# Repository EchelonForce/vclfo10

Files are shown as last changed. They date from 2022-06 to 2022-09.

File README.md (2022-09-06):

# Eurorack LFO VCLFO10 

This is a PCB for a eurorack LFO based on the VCLFO10 chip from Electric Druid.

Full writeup here: https://www.robotdialogs.com/2022/09/eurorack-lfo-module-vclfo10.html

This work is licensed under a Creative Commons Attribution-NonCommercial-ShareAlike 4.0 International License. https://creativecommons.org/licenses/by-nc-sa/4.0/

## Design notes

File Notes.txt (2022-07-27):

v1 issues
 - alternate led stuff should go to output of the lfo filter, it doesn't work with the pwm output of the chip because it doesn't go negative. used a 10k 1/4 watt instead of R51 to go from led stuff to R73, see photo.
 - switches operate backwards from expected, so flipping them on pcb would improve that.
 - zero adjust pot seems to be backwards, would make more sense if it was reversed.

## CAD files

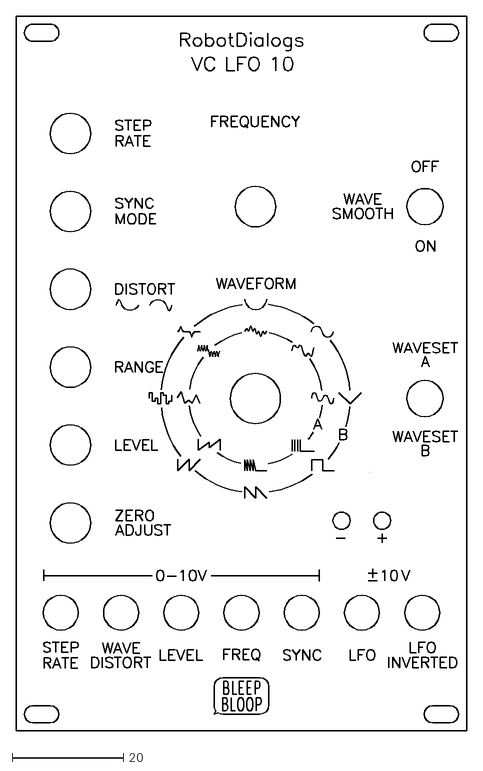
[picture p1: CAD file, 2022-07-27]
front_panel_v1/vclfo10_v1_front_panel_v1.1_engraving.dxf
80.9 x 128.4

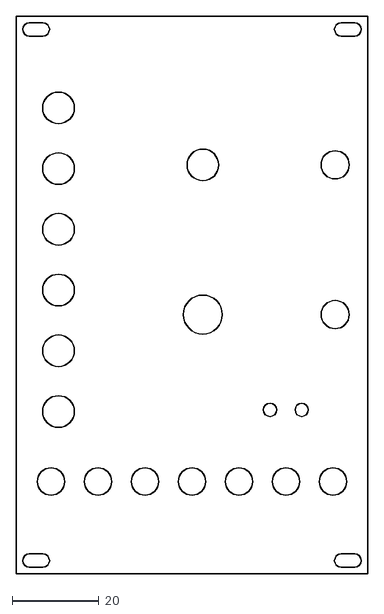
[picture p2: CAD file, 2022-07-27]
front_panel_v1/vclfo10_v1_front_panel_v1.1_no_engraving.dxf
81.0 x 128.5

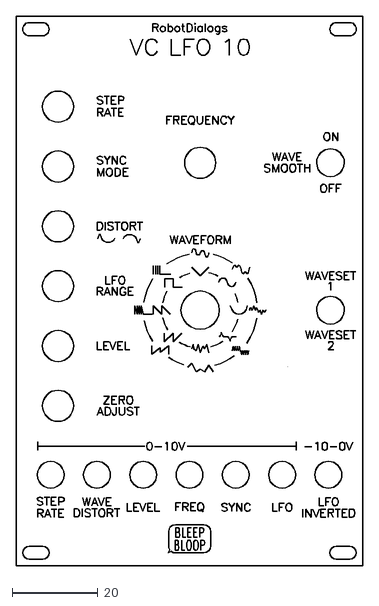
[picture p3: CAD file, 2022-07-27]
front_panel_v1/vclfo10_v1_front_panel_v1_engraving.dxf
80.9 x 128.4

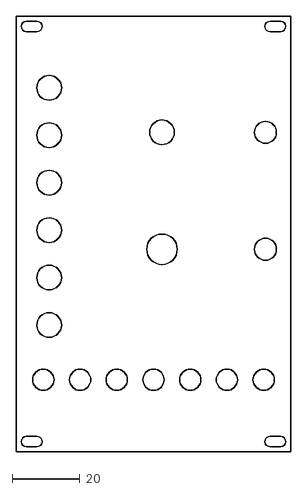
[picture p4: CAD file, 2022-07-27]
front_panel_v1/vclfo10_v1_front_panel_v1_no_engraving.dxf
81.0 x 128.5

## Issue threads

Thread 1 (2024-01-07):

Q's regarding reworking this LFO

KeLaiFu, 2024-01-07:
Hey, first of all, thanks for sharing this monster of an LFO. I have just built it and it's sat in my rack intimidating any 4hp LFOs I have nearby.
I have a few questions, I hope here is an appropriate place to ask.
Firstly, why did you opt for the 358 opamps over the usual TL07X ones?
Second, If I wanted to remove a CV in jack, would it be as simple as just removing it from the schem, as the jacks seem to just patch on to the input coming from the potentiometer.

I plan to make a slightly smaller, reformatted layout to match my other modules, I've got a rough plan but I always end up with a spare jack lying around ruining the feng shui, so I was hoping I could take one out, and maybe use some quad opamps to get the parts down a little.

EchelonForce, 2024-01-11:
Hi, glad to here someone is trying out the design! And yep it's fine to ask here or over on the website comments, whatever works.
I would expect 358s and TL07x's are interchangeable here. I probably just had a lot more 358s at the time. In the tinyurl's on the schematic there are simulators for the sub-circuits so you could experiment with the op-amp parameters in there, but at audio/lfo frequencies I don't think it matters.
You should be able to remove any of the CV jacks, the schematic has switched jacks but it doesn't use that function so removing a jack is just like removing a cable. If there's no jack then that input to the chip doesn't really need to be supplied by +/-12V or run through op-amps, a potentiometer hooked to 5V would work (I think that's what's in the chip's reference schematic).

This was one of my earlier designs. There's a lot I would probably do differently now, quad op-amps would be one of those things.

Make sure you look through the v1 issues on the website: https://www.robotdialogs.com/2022/09/eurorack-lfo-module-vclfo10.html

KeLaiFu, 2024-01-15:
Thanks for the reply.
Yep, currently your overkill LFO found 3 homes here in our SDIY group and I used your mixer layout and a few others in my own modules, so your work is finding a home.

I appreciate the info about the module, I will experiment a little, if I am feeling brave I may use some quad opamps as that would be a help to my revised layout.

Thanks again, and hope to see more added to Robot Dialogs...

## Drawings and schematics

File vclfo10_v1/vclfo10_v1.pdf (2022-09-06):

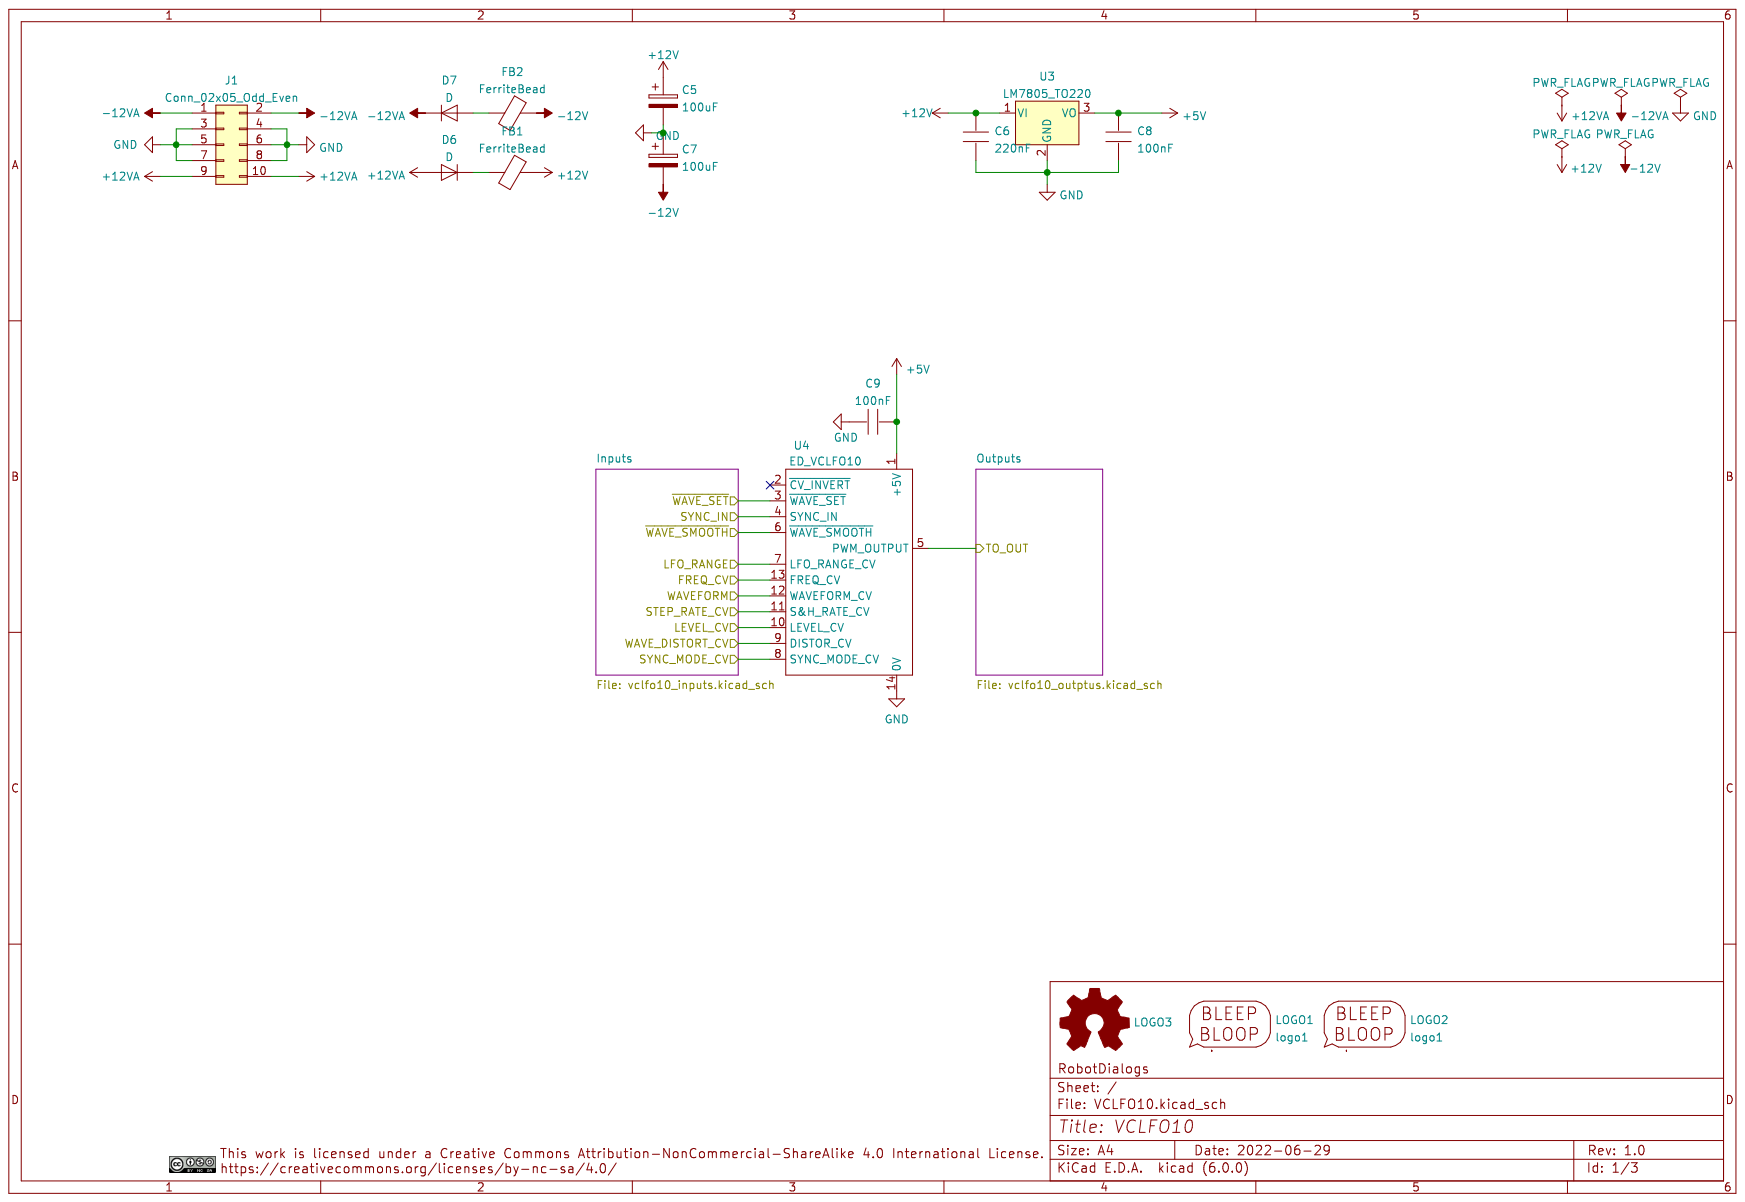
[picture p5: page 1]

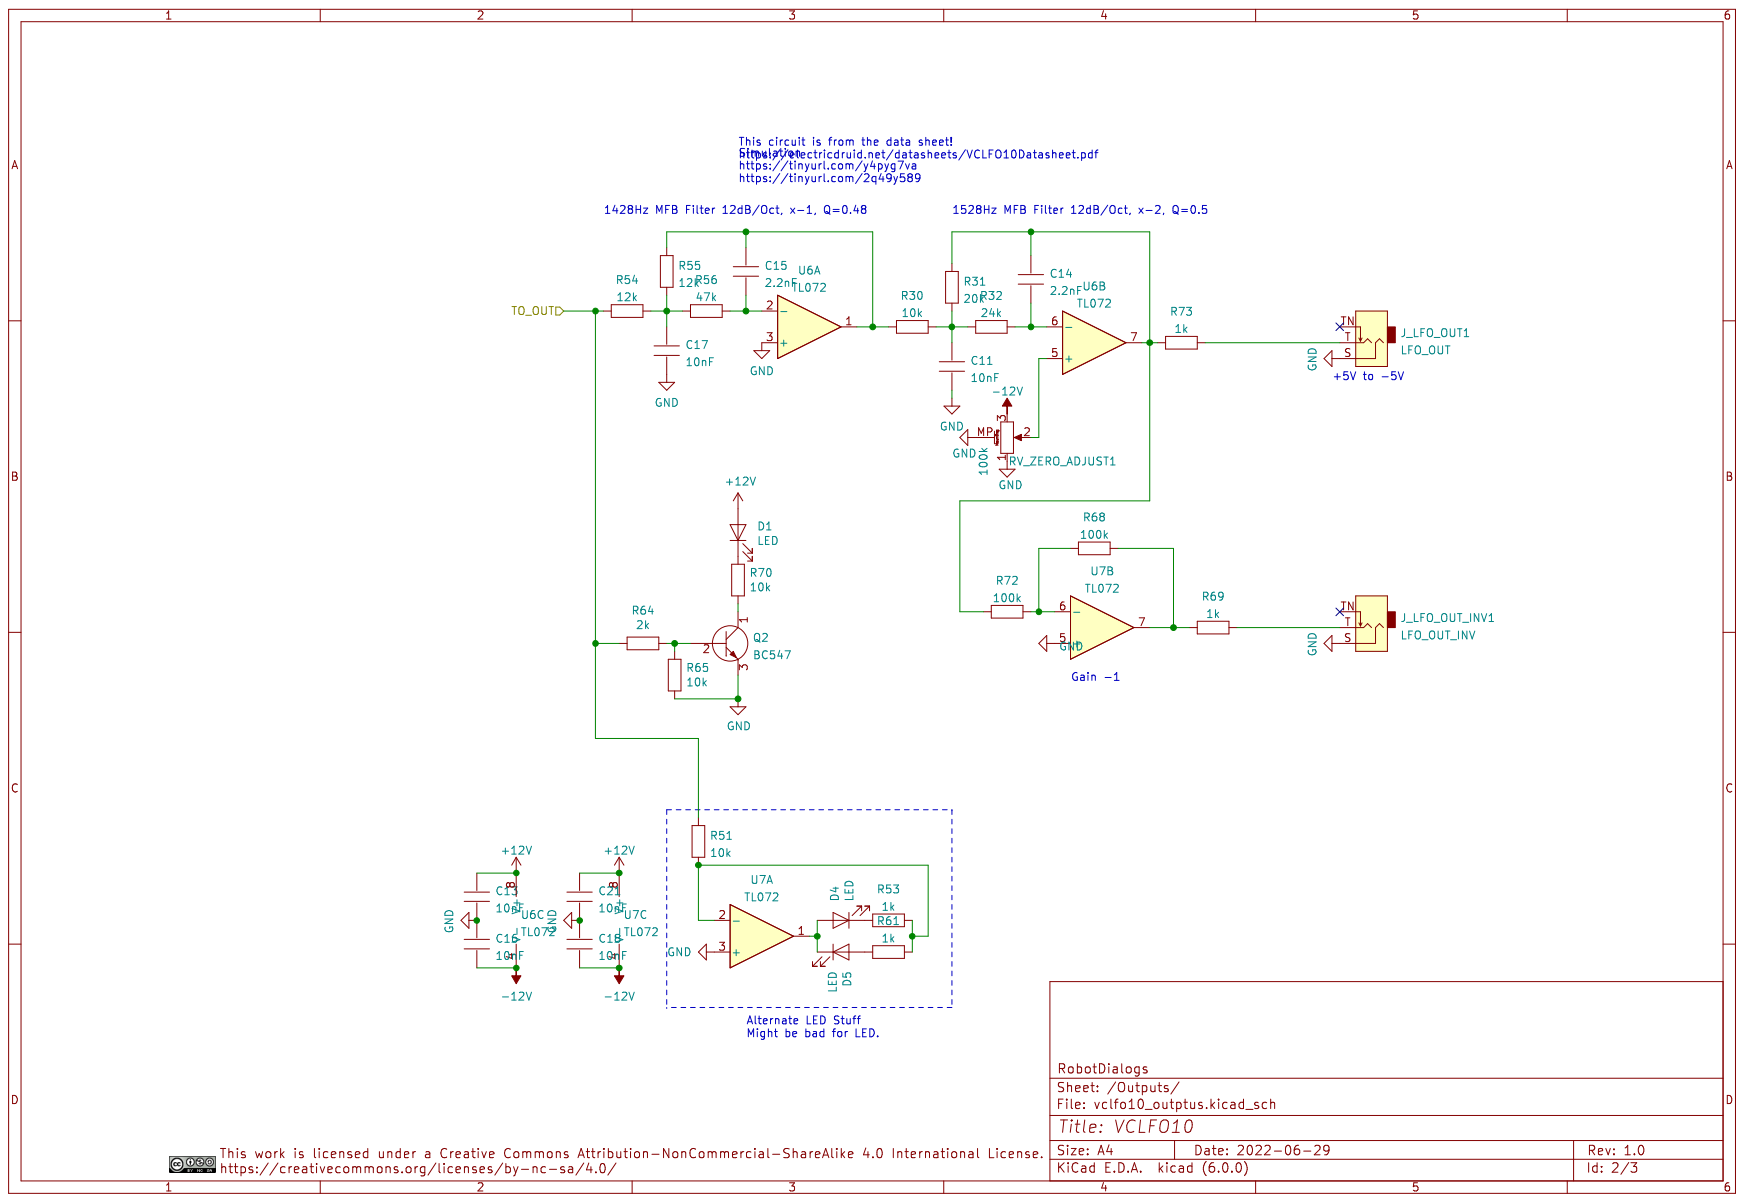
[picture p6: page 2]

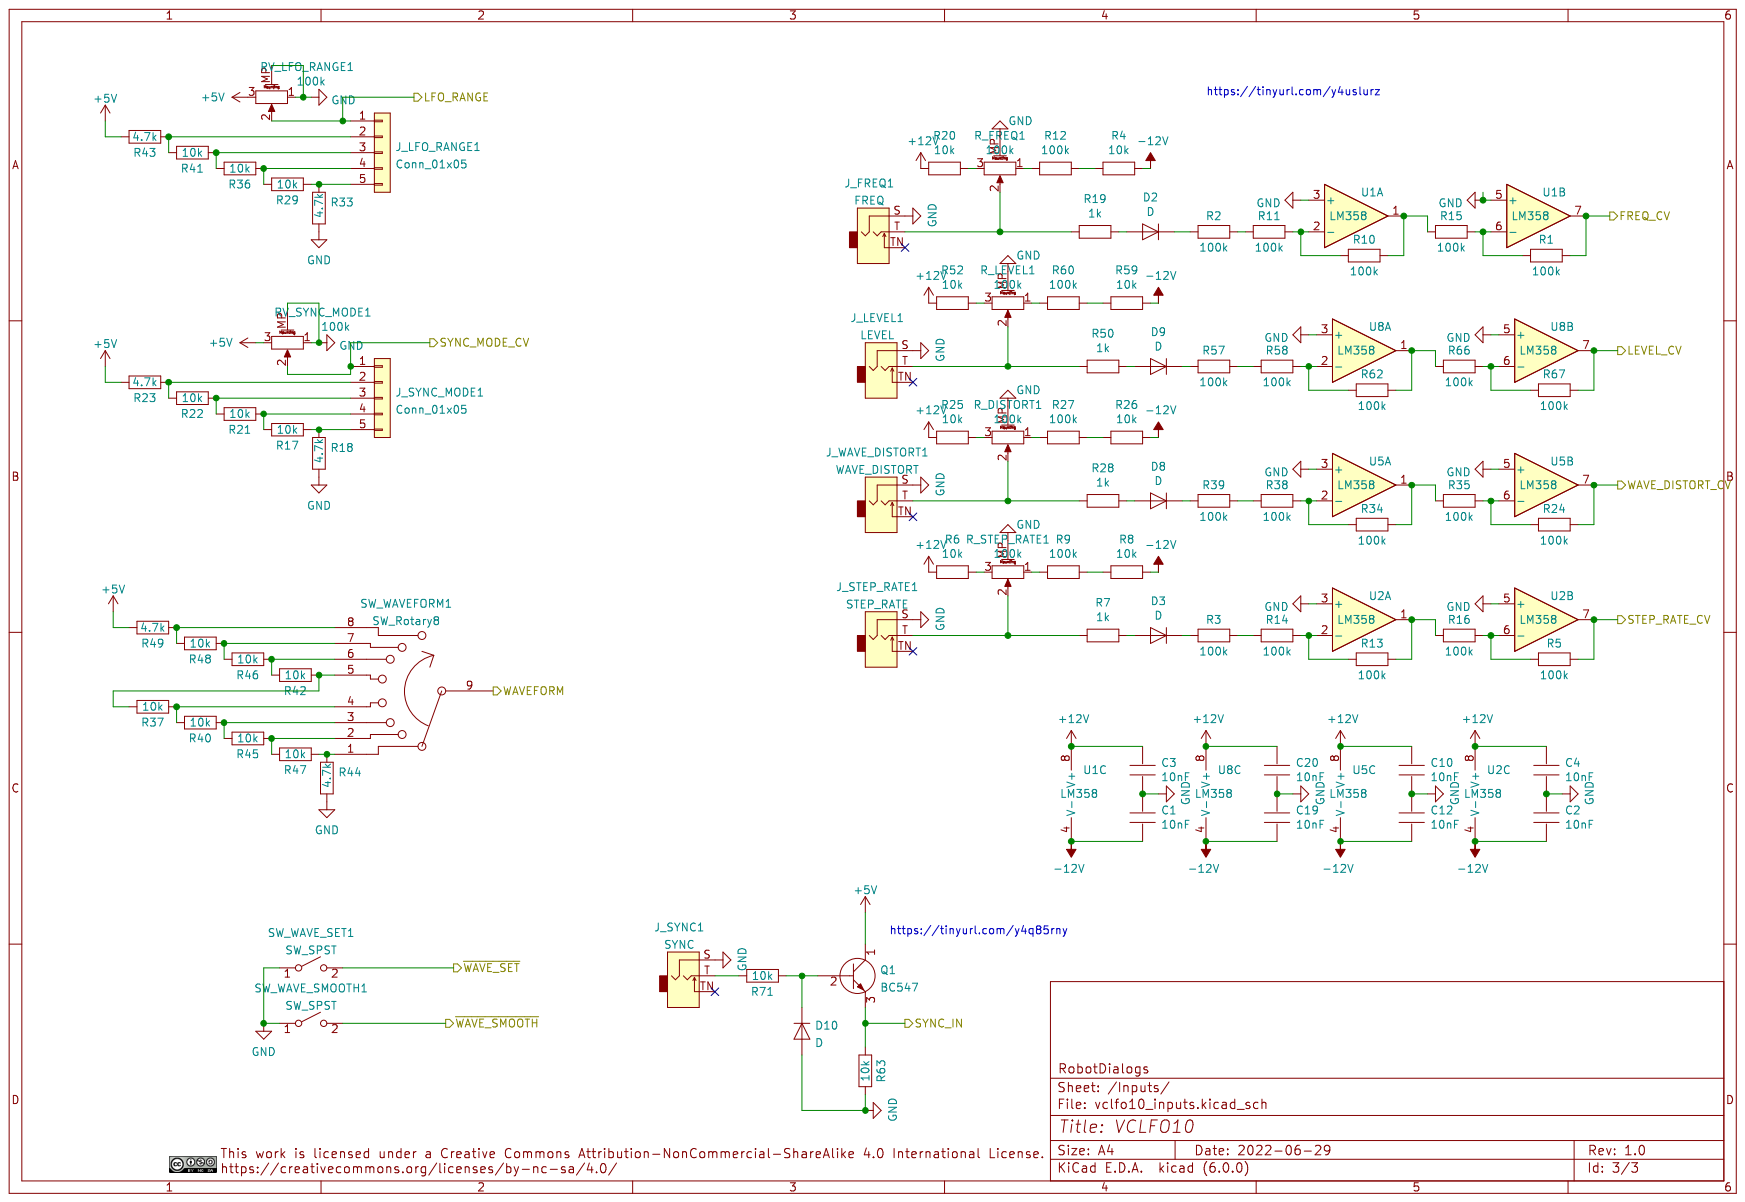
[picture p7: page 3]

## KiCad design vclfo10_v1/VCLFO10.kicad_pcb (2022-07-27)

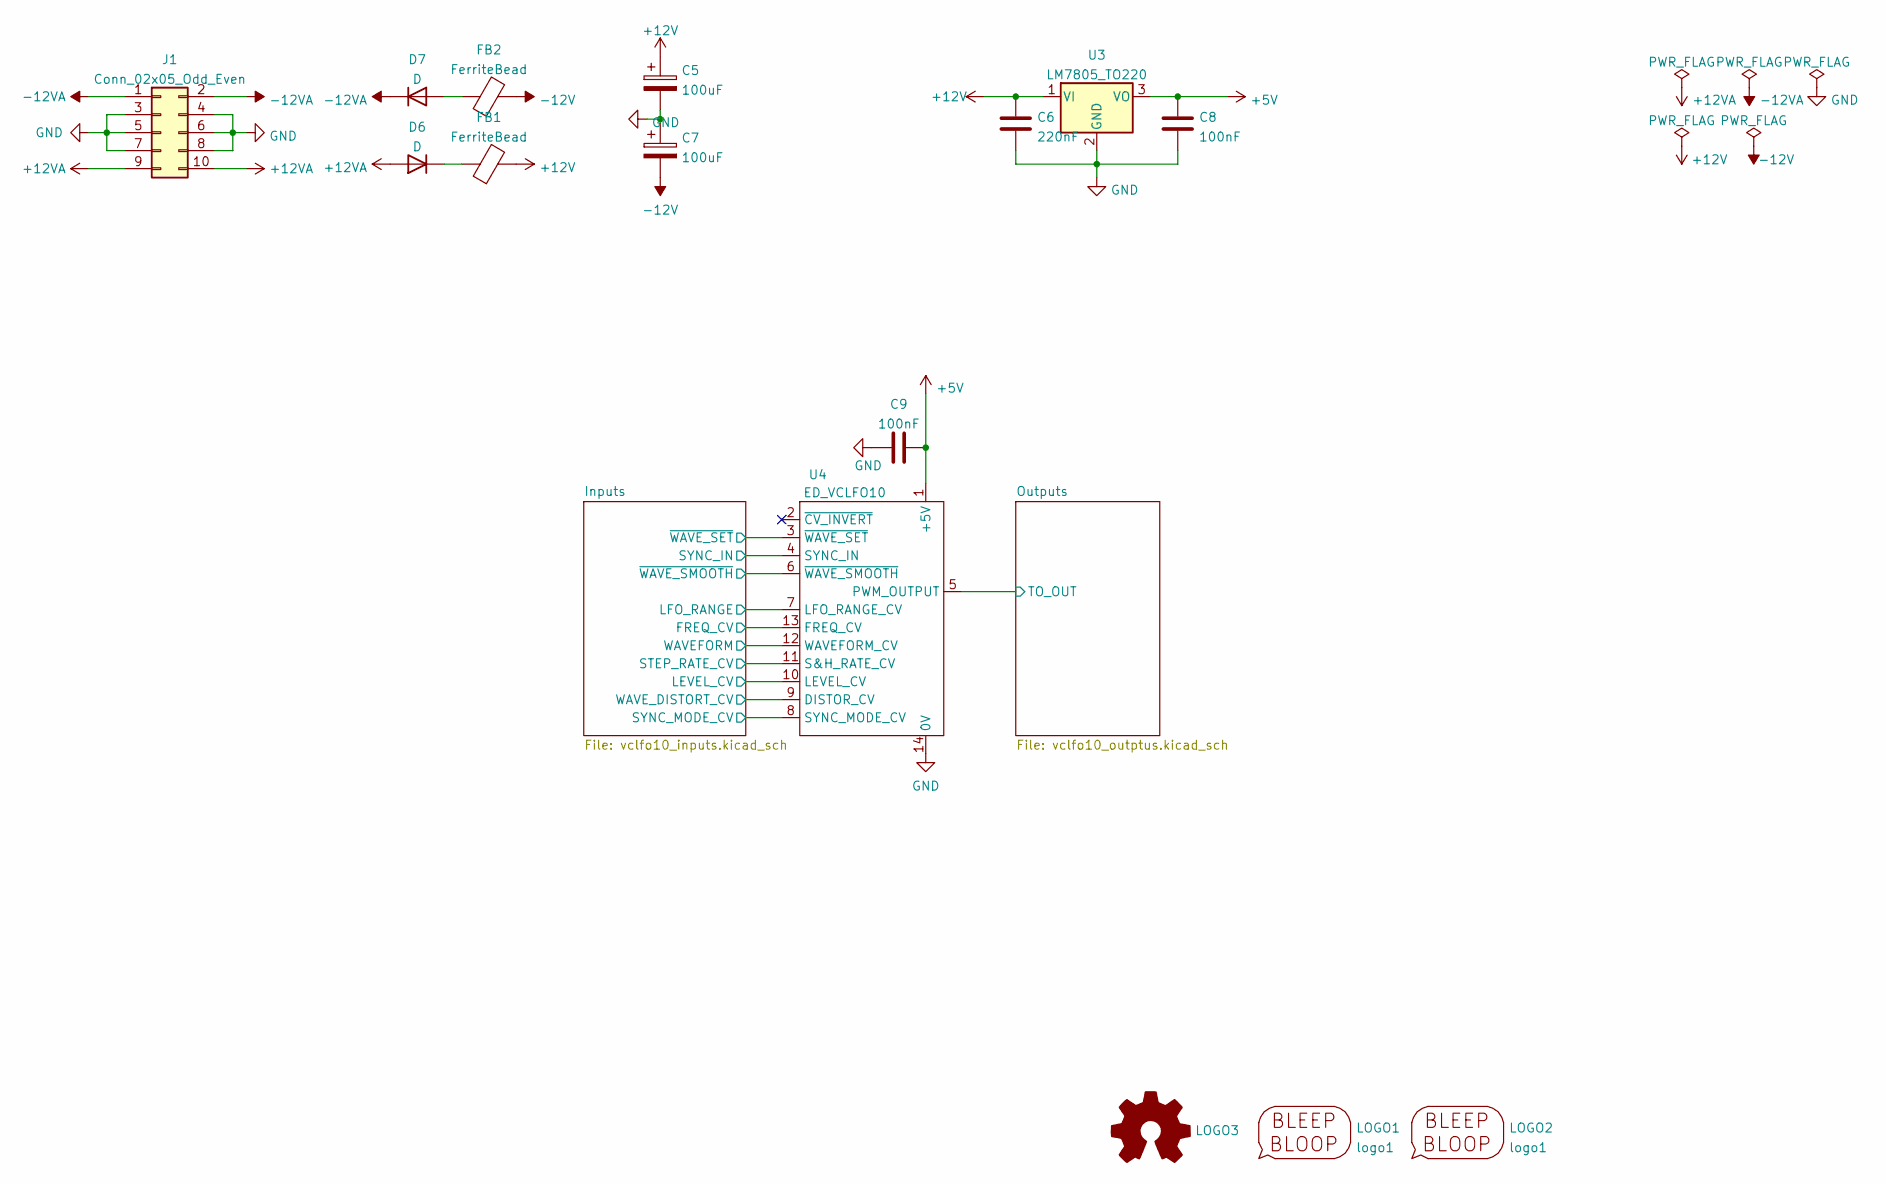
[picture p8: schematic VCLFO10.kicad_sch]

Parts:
C5, C7: 100uF; CP_Radial_D5.0mm_P2.50mm
C6: 220nF; C_1206_3216Metric_Pad1.33x1.80mm_HandSolder
C8, C9: 100nF; C_1206_3216Metric_Pad1.33x1.80mm_HandSolder
D6, D7: D; D_A-405_P7.62mm_Horizontal
FB1, FB2: FerriteBead; L_Axial_L6.6mm_D2.7mm_P2.54mm_Vertical_Vishay_IM-2
J1: Conn_02x05_Odd_Even; IDC-Header_2x05_P2.54mm_Vertical
LOGO1: logo1; Logo1
LOGO2: logo1; Logo2
LOGO3: Logo_Open_Hardware_Small; OSHW-Symbol_6.7x6mm_SilkScreen
U3: LM7805_TO220; TO-220-3_Vertical
U4: ED_VCLFO10; DIP-14_W7.62mm_Socket_LongPads

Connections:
+5V: C8.1, C9.2, U3.3 (VO), U4.1 (+5V); also elsewhere on the board
+12V: C5.1, C6.1, FB1.2, U3.1 (VI); also elsewhere on the board
+12VA: D6.2 (A), J1.9, J1.10
-12V: C7.2, FB2.2; also elsewhere on the board
-12VA: D7.1 (K), J1.1, J1.2
/Inputs/FREQ_CV: U4.13 (FREQ_CV); also elsewhere on the board
/Inputs/LEVEL_CV: U4.10 (LEVEL_CV); also elsewhere on the board
/Inputs/LFO_RANGE: U4.7 (LFO_RANGE_CV); also elsewhere on the board
/Inputs/STEP_RATE_CV: U4.11 (S&H_RATE_CV); also elsewhere on the board
/Inputs/SYNC_IN: U4.4 (SYNC_IN); also elsewhere on the board
/Inputs/SYNC_MODE_CV: U4.8 (SYNC_MODE_CV); also elsewhere on the board
/Inputs/WAVEFORM: U4.12 (WAVEFORM_CV); also elsewhere on the board
/Inputs/WAVE_DISTORT_CV: U4.9 (DISTOR_CV); also elsewhere on the board
/Inputs/~WAVE_SET: U4.3 (~WAVE_SET); also elsewhere on the board
/Inputs/~WAVE_SMOOTH: U4.6 (~WAVE_SMOOTH); also elsewhere on the board
/Outputs/TO_OUT: U4.5 (PWM_OUTPUT); also elsewhere on the board
GND: C5.2, C6.2, C7.1, C8.2, C9.1, J1.3, J1.4, J1.5, J1.6, J1.7, J1.8, U3.2 (GND), U4.14 (0V); also elsewhere on the board
unnamed: D6.1 (K), FB1.1
unnamed: D7.2 (A), FB2.1

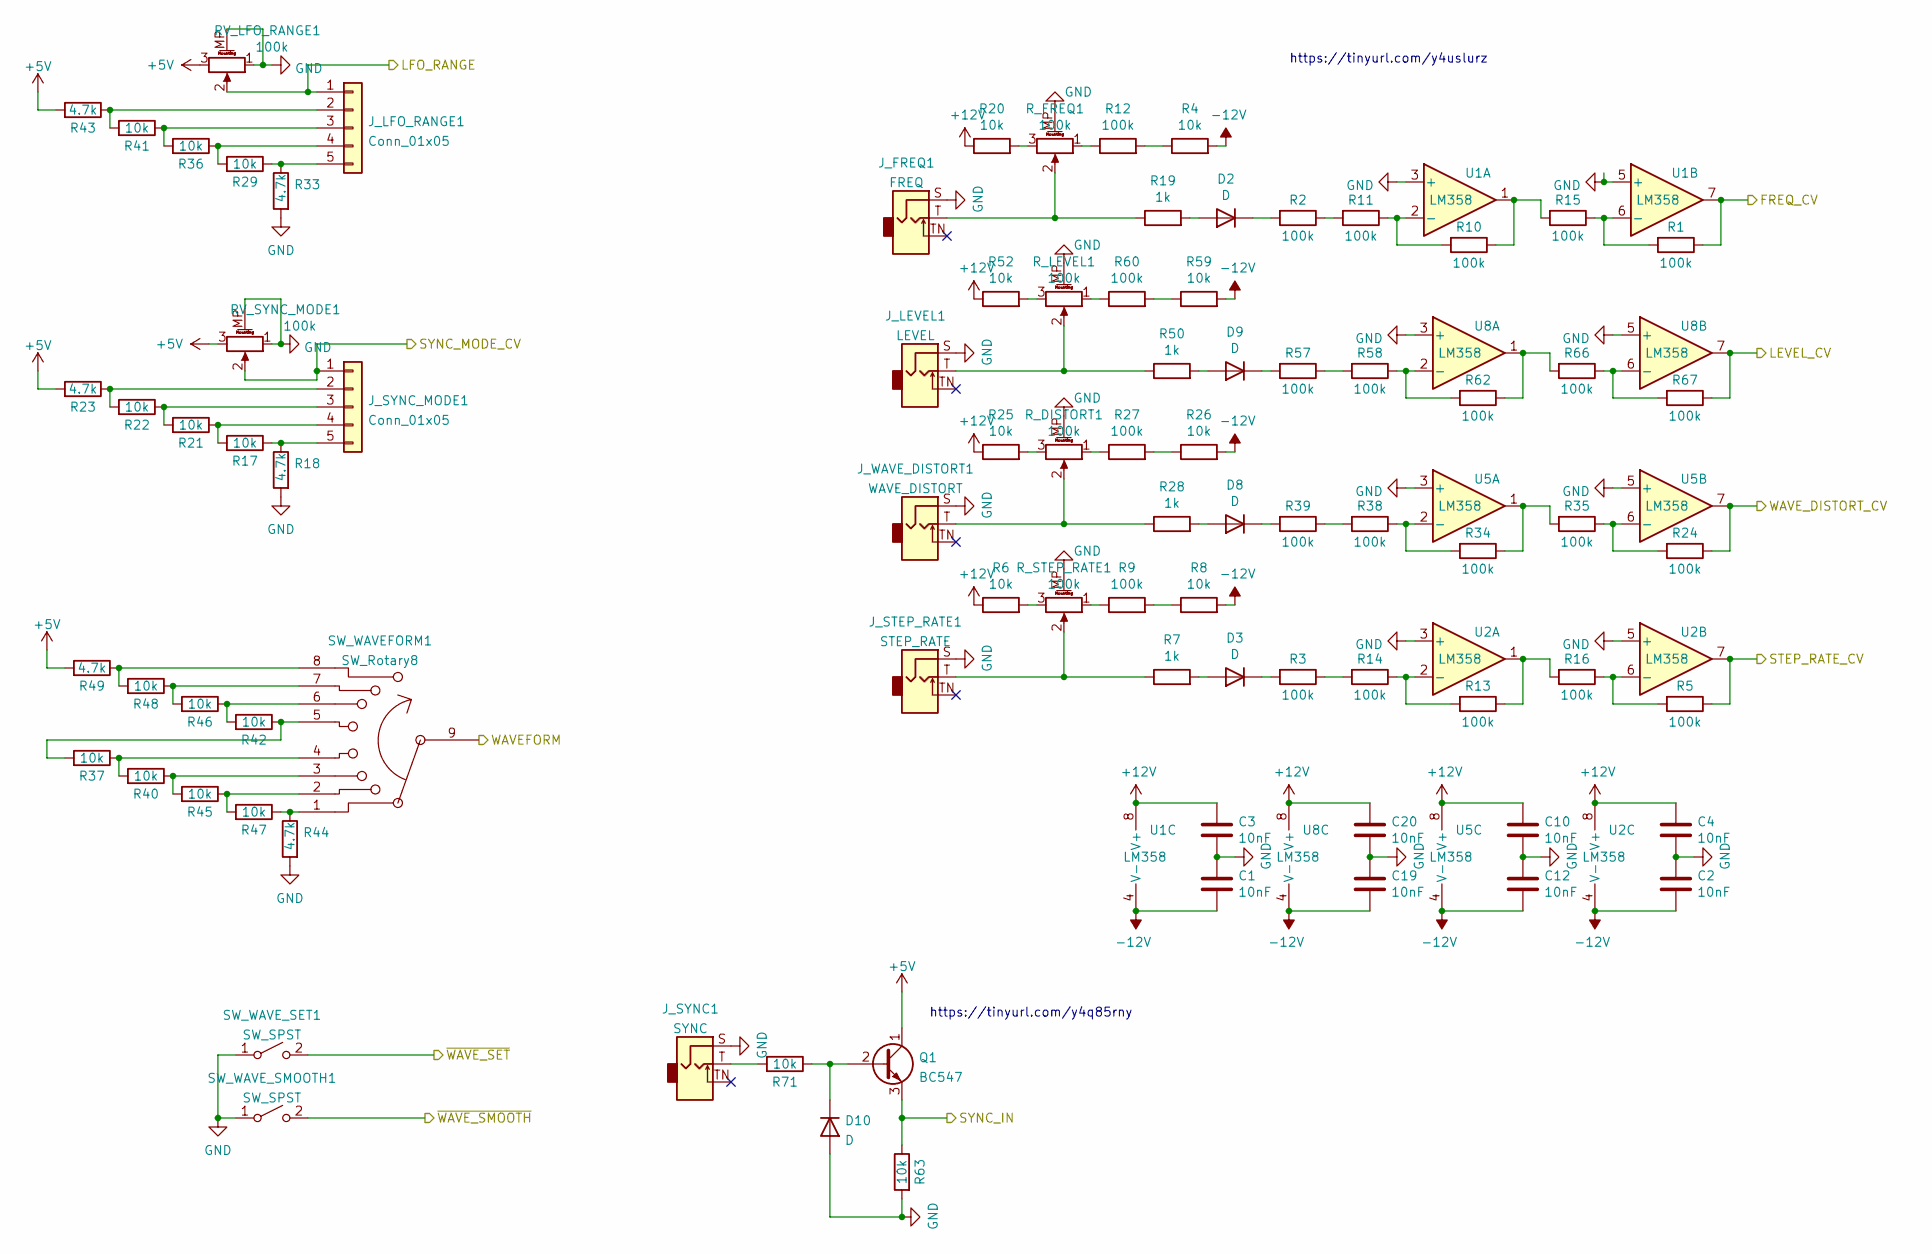
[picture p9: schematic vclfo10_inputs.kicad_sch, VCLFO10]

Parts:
C1, C2, C3, C4, C10, C12, C19, C20: 10nF; C_1206_3216Metric_Pad1.33x1.80mm_HandSolder
D2, D3, D8, D9, D10: D; D_A-405_P7.62mm_Horizontal
J_FREQ1: FREQ; Jack_3.5mm_MJ-355W_and_PJ398SM_Vertical
J_LEVEL1: LEVEL; Jack_3.5mm_MJ-355W_and_PJ398SM_Vertical
J_LFO_RANGE1: Conn_01x05; PinSocket_1x05_P2.54mm_Horizontal_no_silkscreen
J_STEP_RATE1: STEP_RATE; Jack_3.5mm_MJ-355W_and_PJ398SM_Vertical
J_SYNC1: SYNC; Jack_3.5mm_MJ-355W_and_PJ398SM_Vertical
J_SYNC_MODE1: Conn_01x05; PinSocket_1x05_P2.54mm_Horizontal_no_silkscreen
J_WAVE_DISTORT1: WAVE_DISTORT; Jack_3.5mm_MJ-355W_and_PJ398SM_Vertical
Q1: BC547; TO-92_Inline_Wide
R1, R2, R3, R5, R9, R10, R11, R12, R13, R14, R15, R16, R24, R27, R34, R35, R38, R39, R57, R58, R60, R62, R66, R67: 100k; R_1206_3216Metric_Pad1.30x1.75mm_HandSolder
R4, R6, R8, R17, R20, R21, R22, R25, R26, R29, R36, R37, R40, R41, R42, R45, R46, R47, R48, R52, R59, R63, R71: 10k; R_1206_3216Metric_Pad1.30x1.75mm_HandSolder
R7, R19, R28, R50: 1k; R_1206_3216Metric_Pad1.30x1.75mm_HandSolder
R18, R23, R33, R43, R44, R49: 4.7k; R_1206_3216Metric_Pad1.30x1.75mm_HandSolder
RV_LFO_RANGE1: 100k; Potentiometer_Alpha_RD901F-40-00D_Single_Vertical_w_3d
RV_SYNC_MODE1: 100k; Potentiometer_Alpha_RD901F-40-00D_Single_Vertical_w_3d
R_DISTORT1: 100k; Potentiometer_Alpha_RD901F-40-00D_Single_Vertical_w_3d
R_FREQ1: 100k; Potentiometer_Alpha_RD901F-40-00D_Single_Vertical_w_3d
R_LEVEL1: 100k; Potentiometer_Alpha_RD901F-40-00D_Single_Vertical_w_3d
R_STEP_RATE1: 100k; Potentiometer_Alpha_RD901F-40-00D_Single_Vertical_w_3d
SW_WAVEFORM1: SW_Rotary8; 8_position_rotary
SW_WAVE_SET1: SW_SPST; SPDT_Toggle
SW_WAVE_SMOOTH1: SW_SPST; SPDT_Toggle
U1, U2, U5, U8: LM358; DIP-8_W7.62mm_Socket_LongPads

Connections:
+5V: Q1.1 (C), R23.2, R43.2, R49.2, RV_LFO_RANGE1.3, RV_SYNC_MODE1.3; also elsewhere on the board
+12V: C3.2, C4.2, C10.2, C20.2, R6.1, R20.1, R25.1, R52.1, U1.8 (V+), U2.8 (V+), U5.8 (V+), U8.8 (V+); also elsewhere on the board
-12V: C1.1, C2.1, C12.1, C19.1, R4.2, R8.2, R26.2, R59.2, U1.4 (V-), U2.4 (V-), U5.4 (V-), U8.4 (V-); also elsewhere on the board
/Inputs/FREQ_CV: R1.1, U1.7; also elsewhere on the board
/Inputs/LEVEL_CV: R67.1, U8.7; also elsewhere on the board
/Inputs/LFO_RANGE: J_LFO_RANGE1.1, RV_LFO_RANGE1.2; also elsewhere on the board
/Inputs/STEP_RATE_CV: R5.1, U2.7; also elsewhere on the board
/Inputs/SYNC_IN: Q1.3 (E), R63.1; also elsewhere on the board
/Inputs/SYNC_MODE_CV: J_SYNC_MODE1.1, RV_SYNC_MODE1.2; also elsewhere on the board
/Inputs/WAVEFORM: SW_WAVEFORM1.9; also elsewhere on the board
/Inputs/WAVE_DISTORT_CV: R24.1, U5.7; also elsewhere on the board
/Inputs/~WAVE_SET: SW_WAVE_SET1.2 (B); also elsewhere on the board
/Inputs/~WAVE_SMOOTH: SW_WAVE_SMOOTH1.2 (B); also elsewhere on the board
GND: C1.2, C2.2, C3.1, C4.1, C10.1, C12.2, C19.2, C20.1, D10.2 (A), J_FREQ1.S, J_LEVEL1.S, J_STEP_RATE1.S, J_SYNC1.S, J_WAVE_DISTORT1.S, R18.2, R33.2, R44.2, R63.2, RV_LFO_RANGE1.1, RV_LFO_RANGE1.MP (MountPin), RV_SYNC_MODE1.1, RV_SYNC_MODE1.MP (MountPin), R_DISTORT1.MP (MountPin), R_FREQ1.MP (MountPin), R_LEVEL1.MP (MountPin), R_STEP_RATE1.MP (MountPin), SW_WAVE_SET1.1 (A), SW_WAVE_SMOOTH1.1 (A), U1.3 (+), U1.5 (+), U2.3 (+), U2.5 (+), U5.3 (+), U5.5 (+), U8.3 (+), U8.5 (+); also elsewhere on the board
unnamed: D2.1 (K), R2.2
unnamed: D2.2 (A), R19.2
unnamed: D3.1 (K), R3.2
unnamed: D3.2 (A), R7.2
unnamed: D8.1 (K), R39.2
unnamed: D8.2 (A), R28.2
unnamed: D9.1 (K), R57.2
unnamed: D9.2 (A), R50.2
unnamed: D10.1 (K), Q1.2 (B), R71.1
unnamed: J_FREQ1.T, R19.1, R_FREQ1.2
unnamed: J_LEVEL1.T, R50.1, R_LEVEL1.2
unnamed: J_LFO_RANGE1.2, R41.2, R43.1
unnamed: J_LFO_RANGE1.3, R36.2, R41.1
unnamed: J_LFO_RANGE1.4, R29.2, R36.1
unnamed: J_LFO_RANGE1.5, R29.1, R33.1
unnamed: J_STEP_RATE1.T, R7.1, R_STEP_RATE1.2
unnamed: J_SYNC1.T, R71.2
unnamed: J_SYNC_MODE1.2, R22.2, R23.1
unnamed: J_SYNC_MODE1.3, R21.2, R22.1
unnamed: J_SYNC_MODE1.4, R17.2, R21.1
unnamed: J_SYNC_MODE1.5, R17.1, R18.1
unnamed: J_WAVE_DISTORT1.T, R28.1, R_DISTORT1.2
unnamed: R6.2, R_STEP_RATE1.3
unnamed: R9.1, R_STEP_RATE1.1
unnamed: R8.1, R9.2
unnamed: R10.1, R15.2, U1.1
unnamed: R10.2, R11.1, U1.2 (-)
unnamed: R2.1, R11.2
unnamed: R12.1, R_FREQ1.1
unnamed: R4.1, R12.2
unnamed: R13.1, R16.2, U2.1
unnamed: R13.2, R14.1, U2.2 (-)
unnamed: R3.1, R14.2
unnamed: R1.2, R15.1, U1.6 (-)
unnamed: R5.2, R16.1, U2.6 (-)
unnamed: R20.2, R_FREQ1.3
unnamed: R25.2, R_DISTORT1.3
unnamed: R27.1, R_DISTORT1.1
unnamed: R26.1, R27.2
unnamed: R34.1, R35.2, U5.1
unnamed: R24.2, R35.1, U5.6 (-)
unnamed: R37.1, R40.2, SW_WAVEFORM1.4
unnamed: R37.2, R42.1, SW_WAVEFORM1.5
unnamed: R34.2, R38.1, U5.2 (-)
unnamed: R38.2, R39.1
unnamed: R40.1, R45.2, SW_WAVEFORM1.3
unnamed: R45.1, R47.2, SW_WAVEFORM1.2
unnamed: R42.2, R46.1, SW_WAVEFORM1.6
unnamed: R44.1, R47.1, SW_WAVEFORM1.1
unnamed: R46.2, R48.1, SW_WAVEFORM1.7
unnamed: R48.2, R49.1, SW_WAVEFORM1.8
unnamed: R52.2, R_LEVEL1.3
unnamed: R58.1, R62.2, U8.2 (-)
unnamed: R57.1, R58.2
unnamed: R60.1, R_LEVEL1.1
unnamed: R59.1, R60.2
unnamed: R62.1, R66.2, U8.1
unnamed: R66.1, R67.2, U8.6 (-)

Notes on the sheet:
https://tinyurl.com/y4uslurz
https://tinyurl.com/y4q85rny

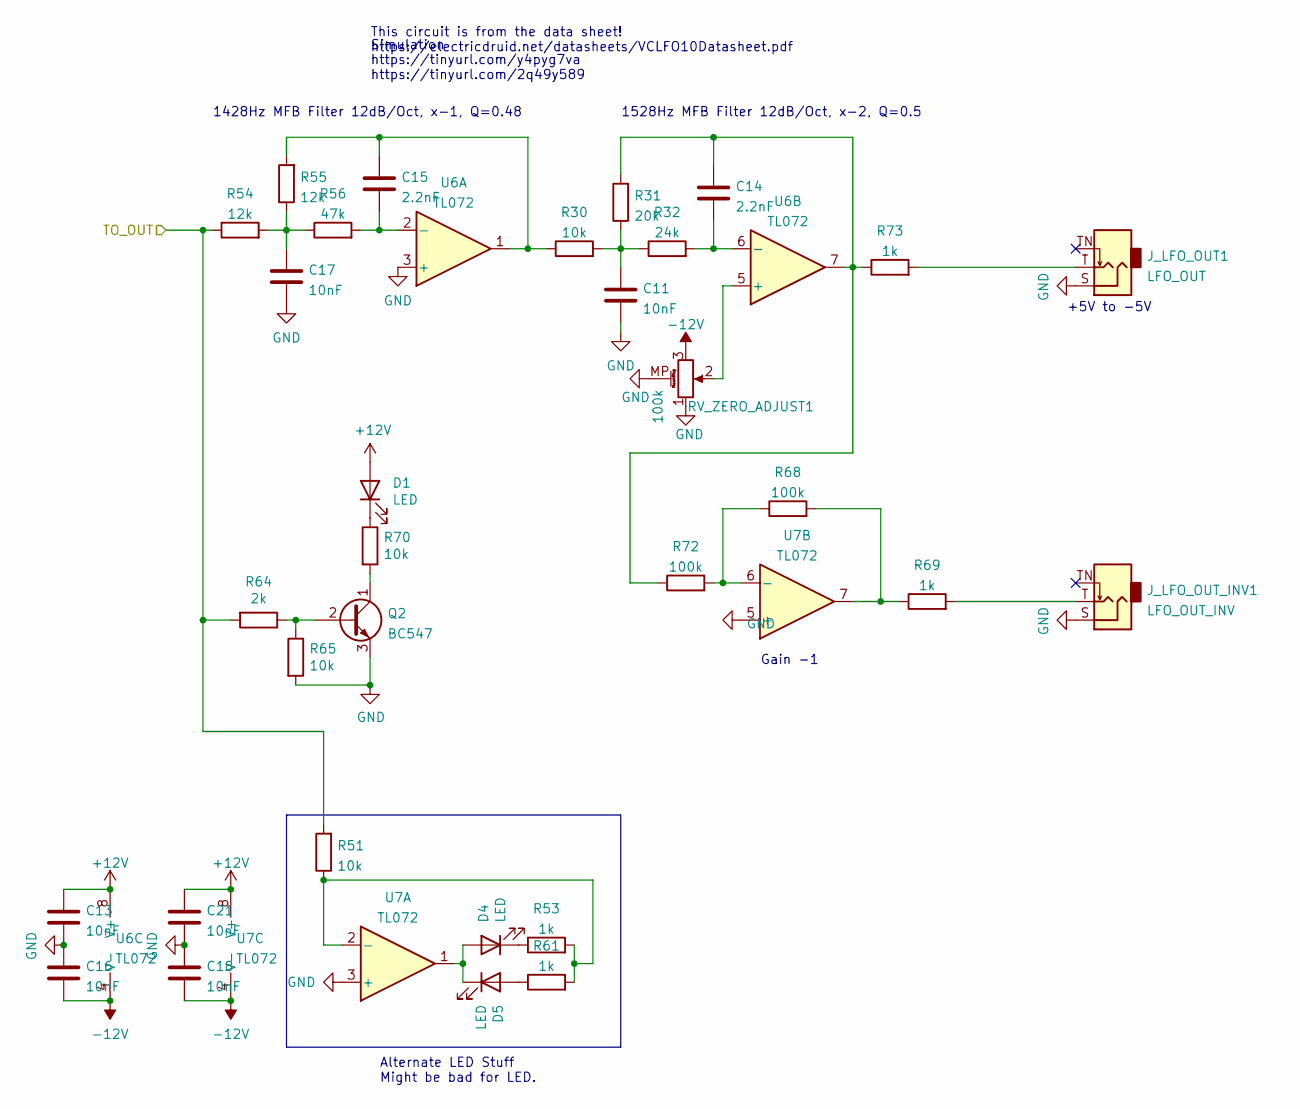
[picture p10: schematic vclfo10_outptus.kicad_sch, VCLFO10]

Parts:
C11, C13, C16, C17, C18, C21: 10nF; C_1206_3216Metric_Pad1.33x1.80mm_HandSolder
C14, C15: 2.2nF; C_1206_3216Metric_Pad1.33x1.80mm_HandSolder
D1, D4, D5: LED; PinHeader_1x02_P2.54mm_Vertical
J_LFO_OUT1: LFO_OUT; Jack_3.5mm_MJ-355W_and_PJ398SM_Vertical
J_LFO_OUT_INV1: LFO_OUT_INV; Jack_3.5mm_MJ-355W_and_PJ398SM_Vertical
Q2: BC547; TO-92_Inline_Wide
R30, R51, R65, R70: 10k; R_1206_3216Metric_Pad1.30x1.75mm_HandSolder
R31: 20k; R_1206_3216Metric_Pad1.30x1.75mm_HandSolder
R32: 24k; R_1206_3216Metric_Pad1.30x1.75mm_HandSolder
R53, R61, R69, R73: 1k; R_1206_3216Metric_Pad1.30x1.75mm_HandSolder
R54, R55: 12k; R_1206_3216Metric_Pad1.30x1.75mm_HandSolder
R56: 47k; R_1206_3216Metric_Pad1.30x1.75mm_HandSolder
R64: 2k; R_1206_3216Metric_Pad1.30x1.75mm_HandSolder
R68, R72: 100k; R_1206_3216Metric_Pad1.30x1.75mm_HandSolder
RV_ZERO_ADJUST1: 100k; Potentiometer_Alpha_RD901F-40-00D_Single_Vertical_w_3d
U6, U7: TL072; DIP-8_W7.62mm_Socket_LongPads

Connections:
+12V: C13.1, C21.1, D1.2 (A), U6.8 (V+), U7.8 (V+); also elsewhere on the board
-12V: C16.2, C18.2, RV_ZERO_ADJUST1.3, U6.4 (V-), U7.4 (V-); also elsewhere on the board
/Outputs/TO_OUT: R51.2, R54.1, R64.2; also elsewhere on the board
GND: C11.2, C13.2, C16.1, C17.2, C18.1, C21.2, J_LFO_OUT1.S, J_LFO_OUT_INV1.S, Q2.3 (E), R65.2, RV_ZERO_ADJUST1.1, RV_ZERO_ADJUST1.MP (MountPin), U6.3 (+), U7.3 (+), U7.5 (+); also elsewhere on the board
unnamed: C11.1, R30.2, R31.1, R32.1
unnamed: C14.1, R31.2, R72.1, R73.1, U6.7
unnamed: C14.2, R32.2, U6.6 (-)
unnamed: C15.1, R30.1, R55.2, U6.1
unnamed: C15.2, R56.2, U6.2 (-)
unnamed: C17.1, R54.2, R55.1, R56.1
unnamed: D1.1 (K), R70.1
unnamed: D4.1 (K), R53.1
unnamed: D4.2 (A), D5.1 (K), U7.1
unnamed: D5.2 (A), R61.1
unnamed: J_LFO_OUT1.T, R73.2
unnamed: J_LFO_OUT_INV1.T, R69.2
unnamed: Q2.1 (C), R70.2
unnamed: Q2.2 (B), R64.1, R65.1
unnamed: R51.1, R53.2, R61.2, U7.2 (-)
unnamed: R68.2, R69.1, U7.7
unnamed: R68.1, R72.2, U7.6 (-)
unnamed: RV_ZERO_ADJUST1.2, U6.5 (+)

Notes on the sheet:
1528Hz MFB Filter 12dB/Oct, x-2, Q=0.5
Simulation https://tinyurl.com/y4pyg7va https://tinyurl.com/2q49y589
1428Hz MFB Filter 12dB/Oct, x-1, Q=0.48
+5V to -5V
This circuit is from the data sheet! https://electricdruid.net/datasheets/VCLFO10Datasheet.pdf
Gain -1
Alternate LED Stuff Might be bad for LED.

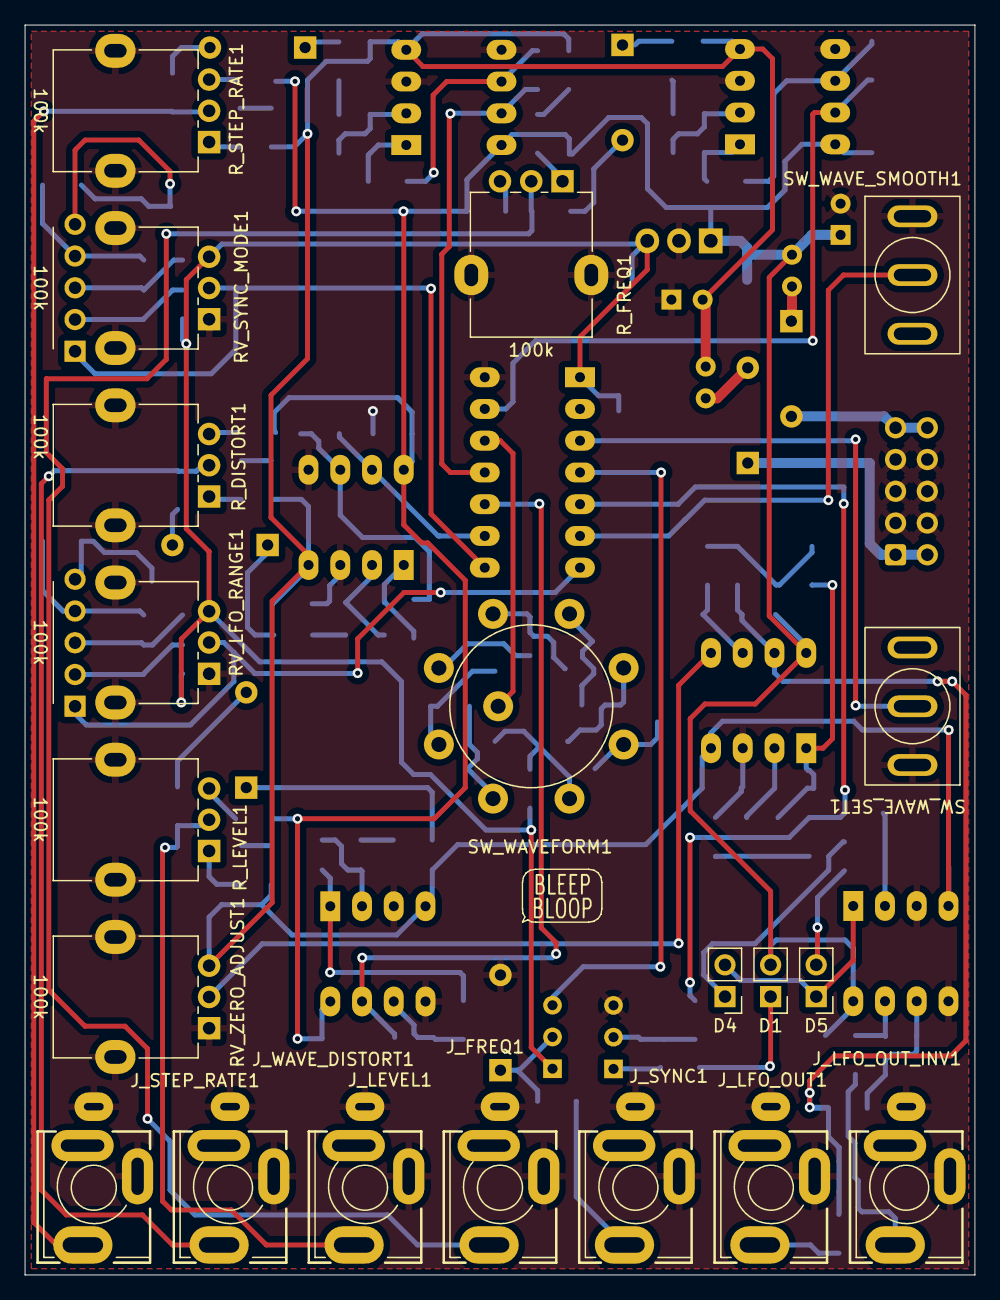
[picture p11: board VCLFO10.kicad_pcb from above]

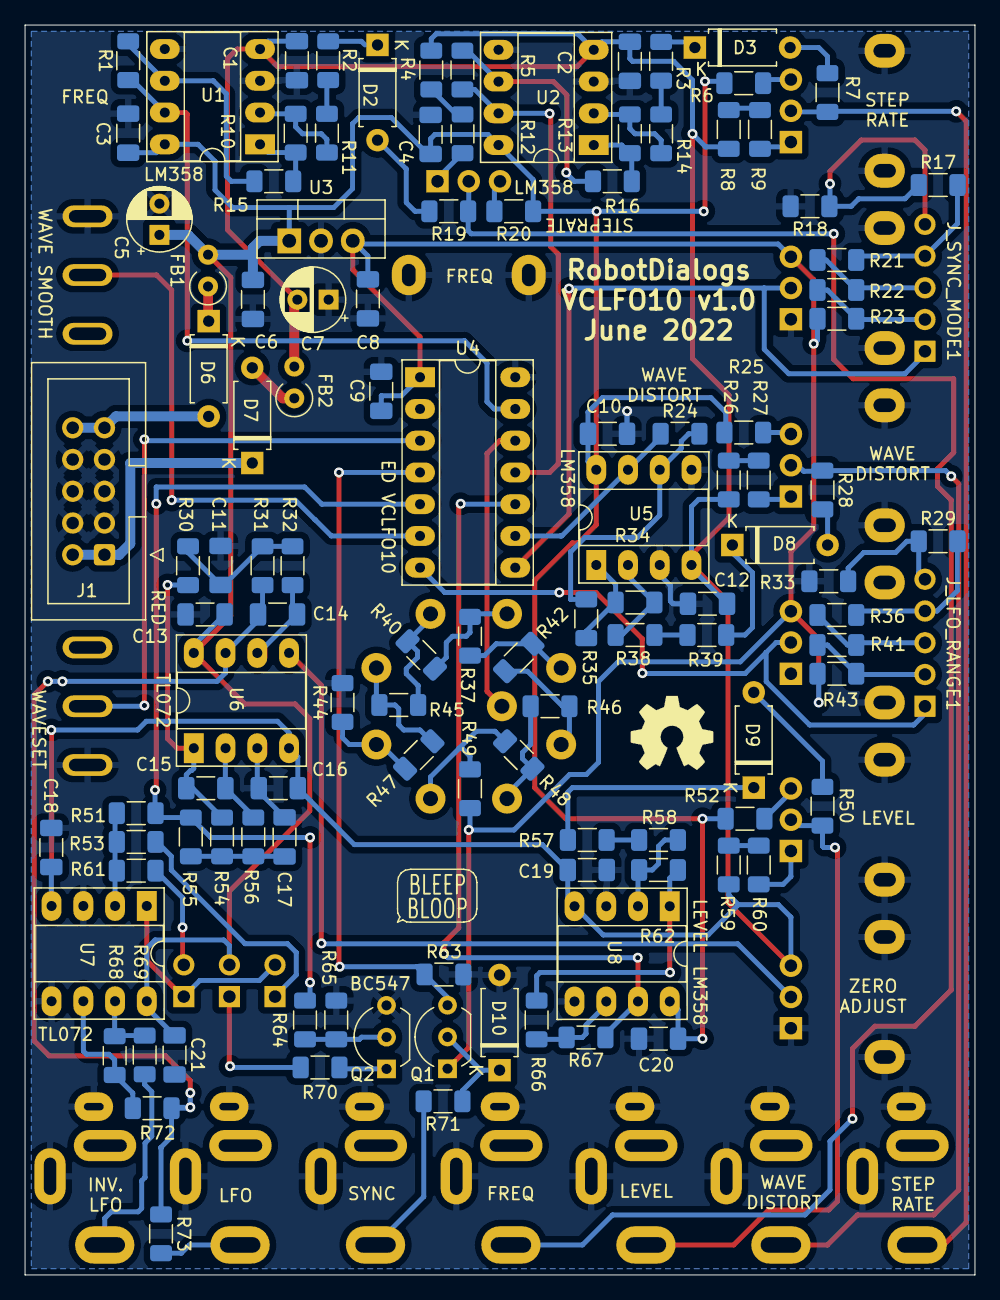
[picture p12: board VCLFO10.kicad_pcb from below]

Board: 2 copper layers, 76.0 x 100.0 mm, 139 parts (117 on the bottom side), 95 nets.

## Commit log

2022-06-28 PCB before routing
    [VCLFO10.kicad_pcb, VCLFO10.kicad_sch, vclfo10_inputs.kicad_sch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]
2022-06-29 Routing done
    [VCLFO10.kicad_pcb, VCLFO10.kicad_sch, vclfo10_inputs.kicad_sch]
2022-06-29 Geographic reannotate and silkscreen cleanup
    [VCLFO10.kicad_pcb, VCLFO10.kicad_sch, vclfo10_inputs.kicad_sch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]
2022-06-29 Added a help text on silkscreen
    [VCLFO10.kicad_pcb]
2022-06-29 Update title block on schematic and pcb sheets
    [VCLFO10.kicad_pcb, VCLFO10.kicad_sch, vclfo10_inputs.kicad_sch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]
2022-07-27 Moved pcb files to sub folder
    [VCLFO10.kicad_pcb, VCLFO10.kicad_sch, vclfo10_inputs.kicad_sch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]
2022-07-27 Front Panel v1 CAD
    [vclfo10_v1_front_panel_v1_engraving.dxf, vclfo10_v1_front_panel_v1_no_engraving.dxf]
2022-07-27 Front Panel v1.1 CAD
    [vclfo10_v1_front_panel_v1.1_engraving.dxf, vclfo10_v1_front_panel_v1.1_no_engraving.dxf]
2022-09-06 Add schematic pdf
